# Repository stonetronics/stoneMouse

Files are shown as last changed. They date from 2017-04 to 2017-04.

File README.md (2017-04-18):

Stonetronics StoneMouse

A vusb-based mouse using a joystick and some buttons

This repository contains
- EAGLE - schematic, board and library
- Source code and atmel studio project

The StoneMouse uses an ATmega8-Controller running at 12 MHz for vusb.
It collects data from an potentiometer joystick and calculates deltax and deltay of the mousecursor. There was the issue that when releasing the Joystick, the adc values of the potis didnt snap back to preciese center values. To fix this an iir filter was implemented in an interval around the center position to determine mean center position and stop the cursor from drifting

These buttons have been implemented:
- left mouse button
- right mouse button
- scroll up
- scroll down
- change precision

The pcb was designed to fit mostly through hole components mounted in an smd-like way, so that there are no spiky through hole junctions on the backside of the pcb.
This was done primaryly to prevent the user from being stung by a through hole junction and because i had only through hole parts lying around
USB-connection is done by an Mini-USB connector

Build summary:
The StoneMouse pcb was etched with natriumpersulfate and the components were soldered. The controller was flashed before it was soldered on the pcb.
For the Joystick, there was a prototyping pcb soldered 90° to the top of the base pcb to hold the components. Several buttons were soldered onto a prototyping pcb which was soldered to the base pcb and the joystick pcb. All buttons are debumped by an 100nF smd capacitor. The mechanical structure was strengthened by pieces of raw pcb soldered to the other pcbs, forming a housing for the electronics.

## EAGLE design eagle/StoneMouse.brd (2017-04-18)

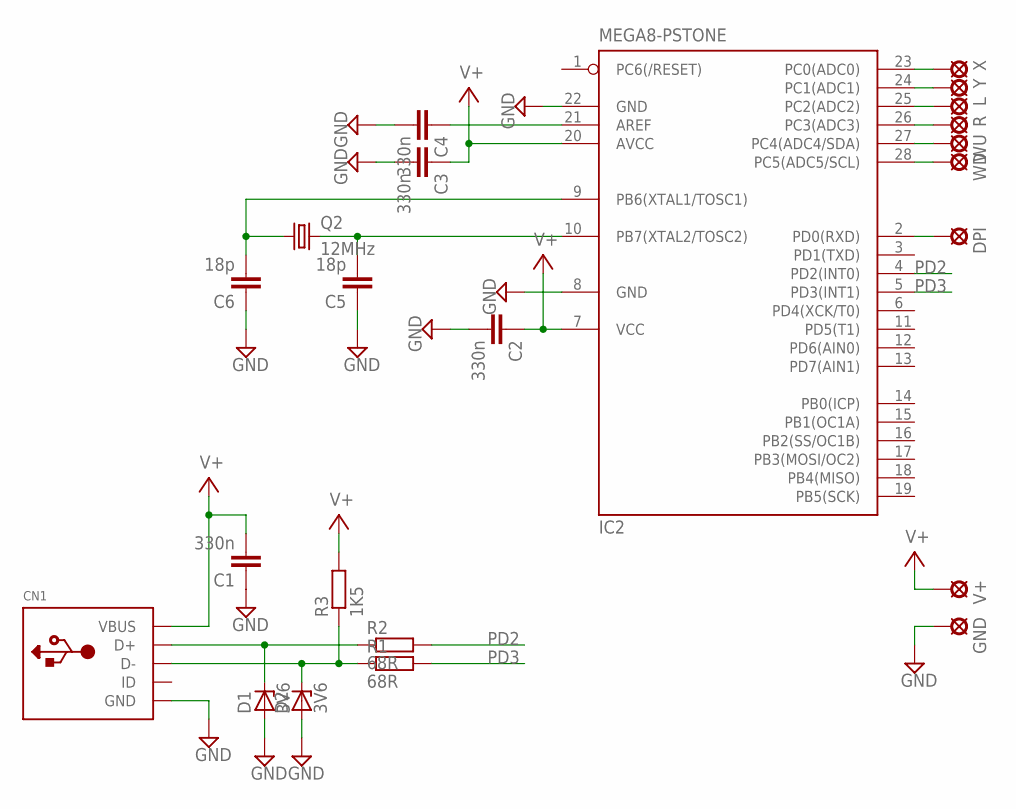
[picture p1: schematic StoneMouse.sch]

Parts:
C1, C2, C3, C4: 330n; 3X7_STONESMD
C5, C6: 18p; 3X7_STONESMD
CN1: USBMINIB; USB-MINIB
D1, D2: 3V6; DO35-7_STONESMD
DPI: SMD3X6
GND: SMD3X6
IC2: MEGA8-PSTONE; DIL28-3_STONESMD
L: SMD3X6
Q2: 12MHz; SM49
R: SMD3X6
R1, R2: 68R; 0204/7_STONESMD
R3: 1K5; 0204/7_STONESMD
V+: SMD3X6
WD: SMD3X6
WU: SMD3X6
X: SMD3X6
Y: SMD3X6

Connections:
GND: C1.P$1 (1), C2.P$2 (2), C3.P$2 (2), C4.P$2 (2), C5.P$1 (1), C6.P$1 (1), CN1.GND, D1.A, D2.A, GND.P$1, IC2.8 (GND), IC2.22 (GND)
unnamed: CN1.D+, D1.K (C), R2.P$1 (1)
unnamed: CN1.D-, D2.K (C), R1.P$1 (1), R3.P$1 (1)
unnamed: C4.P$1 (1), IC2.21 (AREF)
unnamed: DPI.P$1, IC2.2 (PD0(RXD))
unnamed: C6.P$2 (2), IC2.9 (PB6(XTAL1/TOSC1)), Q2.1
unnamed: C5.P$2 (2), IC2.10 (PB7(XTAL2/TOSC2)), Q2.2
unnamed: IC2.24 (PC1(ADC1)), Y.P$1
unnamed: IC2.23 (PC0(ADC0)), X.P$1
unnamed: IC2.25 (PC2(ADC2)), L.P$1
unnamed: IC2.26 (PC3(ADC3)), R.P$1
unnamed: IC2.27 (PC4(ADC4/SDA)), WU.P$1
unnamed: IC2.28 (PC5(ADC5/SCL)), WD.P$1
PD2: IC2.4 (PD2(INT0)), R2.P$2 (2)
PD3: IC2.5 (PD3(INT1)), R1.P$2 (2)
V+: C1.P$2 (2), C2.P$1 (1), C3.P$1 (1), CN1.VBUS, IC2.7 (VCC), IC2.20 (AVCC), R3.P$2 (2), V+.P$1

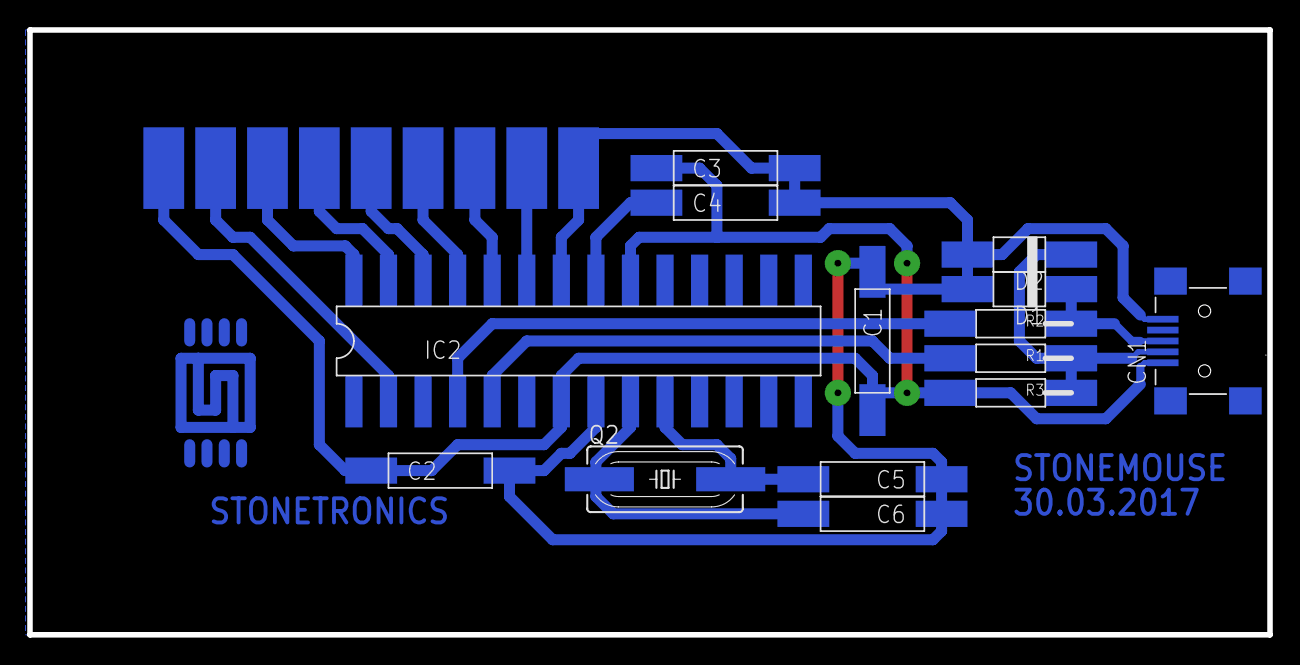
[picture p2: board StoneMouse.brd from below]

Board: 2 copper layers, 91.1 x 44.4 mm, 23 parts (14 on the bottom side), 16 nets.

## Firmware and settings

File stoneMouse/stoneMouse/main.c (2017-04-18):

/* Name: main.c
 * Project: Joystick Mouse (from HID-Mouse Example by Christian Starkjohann)
 * Author: stonetronics
 * Creation Date: 2017.04.18
 * Copyright: (c) 2008 by OBJECTIVE DEVELOPMENT Software GmbH
 * License: GNU GPL v2 (see License.txt), GNU GPL v3 or proprietary (CommercialLicense.txt)
 */

/*
We use VID/PID 0x046D/0xC00E which is taken from a Logitech mouse. Don't
publish any hardware using these IDs! This is for demonstration only!
*/

#define DDR_BUTTONS		DDRC
#define PORT_BUTTONS	PORTC
#define PIN_BUTTONS		PINC
#define ANALOG_X		PC0
#define ANALOG_Y		PC1
#define BUTTON_LMB		PC2
#define BUTTON_RMB		PC3
#define BUTTON_WHEELUP	PC4
#define BUTTON_WHEELDWN	PC5
#define DDR_DPI			DDRD
#define PORT_DPI		PORTD
#define PIN_DPI			PIND
#define BUTTON_DPI		PD0



#define AVG_SIZE	8
#define NORM_THRESHOLD	15
#define F_CPU			12000000

#include <avr/io.h>
#include <avr/wdt.h>
#include <avr/interrupt.h>  /* for sei() */
#include <util/delay.h>     /* for _delay_ms() */

#include <avr/pgmspace.h>   /* required by usbdrv.h */
#include "usbdrv/usbdrv.h"

#include "adc.h" // for adc functions, obviously
//#include "uart.h" // for uart debugging

/* ------------------------------------------------------------------------- */
/* ----------------------------- USB interface ----------------------------- */
/* ------------------------------------------------------------------------- */

PROGMEM const char usbHidReportDescriptor[52] = { /* USB report descriptor, size must match usbconfig.h */
    0x05, 0x01,                    // USAGE_PAGE (Generic Desktop)
    0x09, 0x02,                    // USAGE (Mouse)
    0xa1, 0x01,                    // COLLECTION (Application)
    0x09, 0x01,                    //   USAGE (Pointer)
    0xA1, 0x00,                    //   COLLECTION (Physical)
    0x05, 0x09,                    //     USAGE_PAGE (Button)
    0x19, 0x01,                    //     USAGE_MINIMUM
    0x29, 0x03,                    //     USAGE_MAXIMUM
    0x15, 0x00,                    //     LOGICAL_MINIMUM (0)
    0x25, 0x01,                    //     LOGICAL_MAXIMUM (1)
    0x95, 0x03,                    //     REPORT_COUNT (3)
    0x75, 0x01,                    //     REPORT_SIZE (1)
    0x81, 0x02,                    //     INPUT (Data,Var,Abs)
    0x95, 0x01,                    //     REPORT_COUNT (1)
    0x75, 0x05,                    //     REPORT_SIZE (5)
    0x81, 0x03,                    //     INPUT (Const,Var,Abs)
    0x05, 0x01,                    //     USAGE_PAGE (Generic Desktop)
    0x09, 0x30,                    //     USAGE (X)
    0x09, 0x31,                    //     USAGE (Y)
    0x09, 0x38,                    //     USAGE (Wheel)
    0x15, 0x81,                    //     LOGICAL_MINIMUM (-127)
    0x25, 0x7F,                    //     LOGICAL_MAXIMUM (127)
    0x75, 0x08,                    //     REPORT_SIZE (8)
    0x95, 0x03,                    //     REPORT_COUNT (3)
    0x81, 0x06,                    //     INPUT (Data,Var,Rel)
    0xC0,                          //   END_COLLECTION
    0xC0,                          // END COLLECTION
};
/* This is the same report descriptor as seen in a Logitech mouse. The data
 * described by this descriptor consists of 4 bytes:
 *      .  .  .  .  . B2 B1 B0 .... one byte with mouse button states
 *     X7 X6 X5 X4 X3 X2 X1 X0 .... 8 bit signed relative coordinate x
 *     Y7 Y6 Y5 Y4 Y3 Y2 Y1 Y0 .... 8 bit signed relative coordinate y
 *     W7 W6 W5 W4 W3 W2 W1 W0 .... 8 bit signed relative coordinate wheel
 */
typedef struct{
    uchar   buttonMask;
    char    dx;
    char    dy;
    char    dWheel;
}report_t;

void normXY(uint8_t x, uint8_t y, int8_t* x_norm, int8_t* y_norm);

static report_t reportBuffer;
static uchar    idleRate;   /* repeat rate for keyboards, never used for mice */

/* ------------------------------------------------------------------------- */

usbMsgLen_t usbFunctionSetup(uchar data[8])
{
usbRequest_t    *rq = (void *)data;

    /* The following requests are never used. But since they are required by
     * the specification, we implement them in this example.
     */
    if((rq->bmRequestType & USBRQ_TYPE_MASK) == USBRQ_TYPE_CLASS){    /* class request type */
        if(rq->bRequest == USBRQ_HID_GET_REPORT){  /* wValue: ReportType (highbyte), ReportID (lowbyte) */
            /* we only have one report type, so don't look at wValue */
            usbMsgPtr = (void *)&reportBuffer;
            return sizeof(reportBuffer);
        }else if(rq->bRequest == USBRQ_HID_GET_IDLE){
            usbMsgPtr = &idleRate;
            return 1;
        }else if(rq->bRequest == USBRQ_HID_SET_IDLE){
            idleRate = rq->wValue.bytes[1];
        }
    }else{
        /* no vendor specific requests implemented */
    }
    return 0;   /* default for not implemented requests: return no data back to host */
}

/* ------------------------------------------------------------------------- */

int __attribute__((noreturn)) main(void)
{
	uchar   i;
	uint8_t x_raw;
	uint8_t y_raw;
	int8_t x_norm;
	int8_t y_norm;
	uint8_t dpi_factor = 2;

	uint8_t button_lmb;
	uint8_t button_rmb;
	uint8_t button_wheelup;
	uint8_t button_wheeldwn;
	uint8_t button_dpi;
	uint8_t button_dpi_old;

	/* init button ports & stuff */
	//set all buttons and analog inputs to input
	DDR_BUTTONS &= ~((1<<ANALOG_X) | (1<<ANALOG_Y) | (1<<BUTTON_LMB) | (1<<BUTTON_RMB) | (1<<BUTTON_WHEELUP) | (1<<BUTTON_WHEELDWN));
	DDR_DPI &= ~(1<<BUTTON_DPI);
	//set pullups on all buttons
	PORT_BUTTONS |= (1<<BUTTON_LMB) | (1<<BUTTON_RMB) | (1<<BUTTON_WHEELUP) | (1<<BUTTON_WHEELDWN);
	PORT_DPI |= (1<<BUTTON_DPI);
	button_dpi_old = PIN_DPI & (1<<BUTTON_DPI);

	adc_init();
	//uart_init();
    wdt_enable(WDTO_1S); //needed
    usbInit();
    usbDeviceDisconnect();  /* enforce re-enumeration, do this while interrupts are disabled! */
    i = 0;
    while(--i){             /* fake USB disconnect for > 250 ms */
        wdt_reset();
        _delay_ms(1);
    }

    usbDeviceConnect();
    sei();
    while(1){                /* main event loop */
        wdt_reset();
        usbPoll();
		if(usbInterruptIsReady()){
            /* called after every poll of the interrupt endpoint */
            usbSetInterrupt((void *)&reportBuffer, sizeof(reportBuffer));
        }

		/*button inputs handling*/
		//scan all buttons
		button_rmb = PIN_BUTTONS & (1<<BUTTON_RMB);
		button_lmb = PIN_BUTTONS & (1<<BUTTON_LMB);
		button_wheelup = PIN_BUTTONS & (1<<BUTTON_WHEELUP);
		button_wheeldwn = PIN_BUTTONS & (1<<BUTTON_WHEELDWN);
		button_dpi = PIN_DPI & (1<<BUTTON_DPI);

		if(!button_lmb)
			reportBuffer.buttonMask |= (1<<0); //activate left mousebutton
		else
			reportBuffer.buttonMask &= ~(1<<0); //deactivate left mousebutton

		if(!button_rmb)
			reportBuffer.buttonMask |= (1<<1); //activate right mousebutton
		else
			reportBuffer.buttonMask &= ~(1<<1); //deactivate right mousebutton
		
		//button emulated mousewheel
		if(!button_wheelup)
			reportBuffer.dWheel = 10/dpi_factor;
		else if(!button_wheeldwn)
			reportBuffer.dWheel = -10/dpi_factor;
		else
			reportBuffer.dWheel = 0;

		//if dpi button pressed switch through various dpi factors
		if(button_dpi != button_dpi_old)
		{
			button_dpi_old = button_dpi;
			if(!button_dpi)
			{
				switch(dpi_factor)
				{
					case 1:
						dpi_factor = 2;
						break;
					case 2:
						dpi_factor = 5;
						break;
					case 5:
						dpi_factor = 10;
						break;
					case 10:
						dpi_factor = 1;
						break;
					default:
						dpi_factor = 2;
						break;
				}
			}
		}
		
		//joystick input stuff
		if(adc_updateValues(&(x_raw), &(y_raw)))
		{	
			normXY(x_raw, y_raw, &x_norm, &y_norm );
			reportBuffer.dx = x_norm/dpi_factor;
			reportBuffer.dy = y_norm/dpi_factor;
		}

    }
}


void normXY(uint8_t x, uint8_t y, int8_t* x_norm, int8_t* y_norm)
{
	static uint8_t firstrun = 1;
	static float x_avg = 128;
	static uint8_t x_upperThreshold = 130;
	static uint8_t x_lowerThreshold = 120;
	static float y_avg = 128;
	static uint8_t y_upperThreshold = 130;
	static uint8_t y_lowerThreshold = 120;

	if(firstrun)
	{
		x_avg = (float)x;
		x_upperThreshold = x_avg + NORM_THRESHOLD;
		x_lowerThreshold = x_avg - NORM_THRESHOLD;
		y_avg = (float)y;
		y_upperThreshold = y_avg + NORM_THRESHOLD;
		y_lowerThreshold = y_avg - NORM_THRESHOLD;
		firstrun = 0;
	}

	if ((x > x_lowerThreshold) && (x < x_upperThreshold))
	{
		x_avg = x_avg * ((float)(AVG_SIZE - 1)/AVG_SIZE) + ((float)x) * 1/((float) AVG_SIZE);
	}

	if ((y > (y_lowerThreshold)) && (y < (y_upperThreshold)))
	{
		y_avg = y_avg * ((float)(AVG_SIZE - 1)/AVG_SIZE) + ((float)y) * 1/((float) AVG_SIZE);
	}

	*x_norm =(int8_t)( ((float) x) - x_avg );
	*y_norm =(int8_t)( y_avg - ((float) y) );
}
/* ------------------------------------------------------------------------- */

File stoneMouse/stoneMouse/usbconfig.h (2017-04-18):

/* Name: usbconfig.h
 * Project: V-USB, virtual USB port for Atmel's(r) AVR(r) microcontrollers
 * Author: Christian Starkjohann
 * Creation Date: 2005-04-01
 * Tabsize: 4
 * Copyright: (c) 2005 by OBJECTIVE DEVELOPMENT Software GmbH
 * License: GNU GPL v2 (see License.txt), GNU GPL v3 or proprietary (CommercialLicense.txt)
 */

#ifndef __usbconfig_h_included__
#define __usbconfig_h_included__

/*
General Description:
This file is an example configuration (with inline documentation) for the USB
driver. It configures V-USB for USB D+ connected to Port D bit 2 (which is
also hardware interrupt 0 on many devices) and USB D- to Port D bit 4. You may
wire the lines to any other port, as long as D+ is also wired to INT0 (or any
other hardware interrupt, as long as it is the highest level interrupt, see
section at the end of this file).
*/

/* ---------------------------- Hardware Config ---------------------------- */

#define USB_CFG_IOPORTNAME      D
/* This is the port where the USB bus is connected. When you configure it to
 * "B", the registers PORTB, PINB and DDRB will be used.
 */
#define USB_CFG_DMINUS_BIT      3
/* This is the bit number in USB_CFG_IOPORT where the USB D- line is connected.
 * This may be any bit in the port.
 */
#define USB_CFG_DPLUS_BIT       2
/* This is the bit number in USB_CFG_IOPORT where the USB D+ line is connected.
 * This may be any bit in the port. Please note that D+ must also be connected
 * to interrupt pin INT0! [You can also use other interrupts, see section
 * "Optional MCU Description" below, or you can connect D- to the interrupt, as
 * it is required if you use the USB_COUNT_SOF feature. If you use D- for the
 * interrupt, the USB interrupt will also be triggered at Start-Of-Frame
 * markers every millisecond.]
 */
#define USB_CFG_CLOCK_KHZ       12000
/* Clock rate of the AVR in kHz. Legal values are 12000, 12800, 15000, 16000,
 * 16500, 18000 and 20000. The 12.8 MHz and 16.5 MHz versions of the code
 * require no crystal, they tolerate +/- 1% deviation from the nominal
 * frequency. All other rates require a precision of 2000 ppm and thus a
 * crystal!
 * Since F_CPU should be defined to your actual clock rate anyway, you should
 * not need to modify this setting.
 */
#define USB_CFG_CHECK_CRC       0
/* Define this to 1 if you want that the driver checks integrity of incoming
 * data packets (CRC checks). CRC checks cost quite a bit of code size and are
 * currently only available for 18 MHz crystal clock. You must choose
 * USB_CFG_CLOCK_KHZ = 18000 if you enable this option.
 */

/* ----------------------- Optional Hardware Config ------------------------ */

/* #define USB_CFG_PULLUP_IOPORTNAME   D */
/* If you connect the 1.5k pullup resistor from D- to a port pin instead of
 * V+, you can connect and disconnect the device from firmware by calling
 * the macros usbDeviceConnect() and usbDeviceDisconnect() (see usbdrv.h).
 * This constant defines the port on which the pullup resistor is connected.
 */
/* #define USB_CFG_PULLUP_BIT          4 */
/* This constant defines the bit number in USB_CFG_PULLUP_IOPORT (defined
 * above) where the 1.5k pullup resistor is connected. See description
 * above for details.
 */

/* --------------------------- Functional Range ---------------------------- */
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
